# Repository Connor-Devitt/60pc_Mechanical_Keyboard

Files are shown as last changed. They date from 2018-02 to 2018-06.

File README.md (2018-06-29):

# 60pc_Mechanical_Keyboard
60% size mechanical keyboard design including PCB, frame, firmware. 

## The PCB (kiCAD)
* PCB uses a 60% keyboard layout
* Footprints for Cherry MX and clones.
* Microcontroller is ATmega32u4.
* Interfaces to PC over USB micro.

## The Frame (Inventor 2018)
* Made out of sheet aluminum
* Cutouts for cherry style stabilizers
* Approximatly 5 degree slope

## Versions
Version 1.0: Initial release
Version 1.1: Smaller form factor and improved differential routing

## Pictures (v1.0)
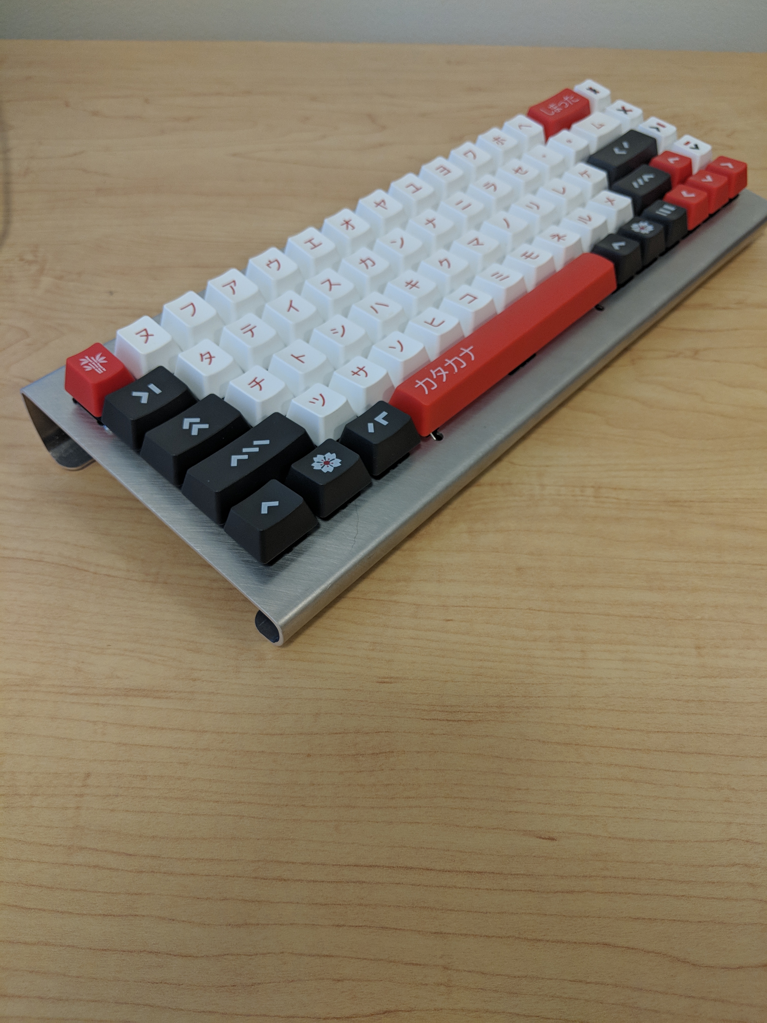
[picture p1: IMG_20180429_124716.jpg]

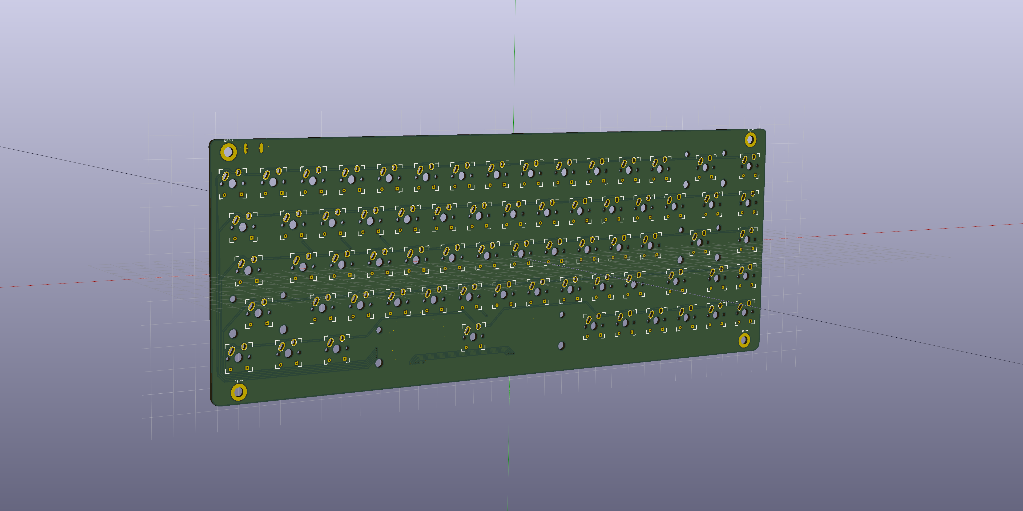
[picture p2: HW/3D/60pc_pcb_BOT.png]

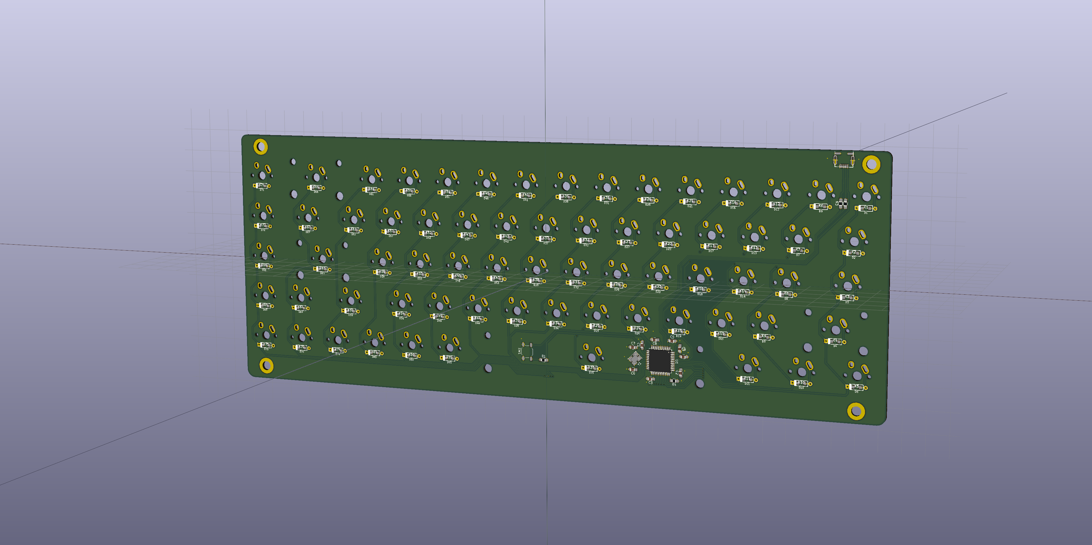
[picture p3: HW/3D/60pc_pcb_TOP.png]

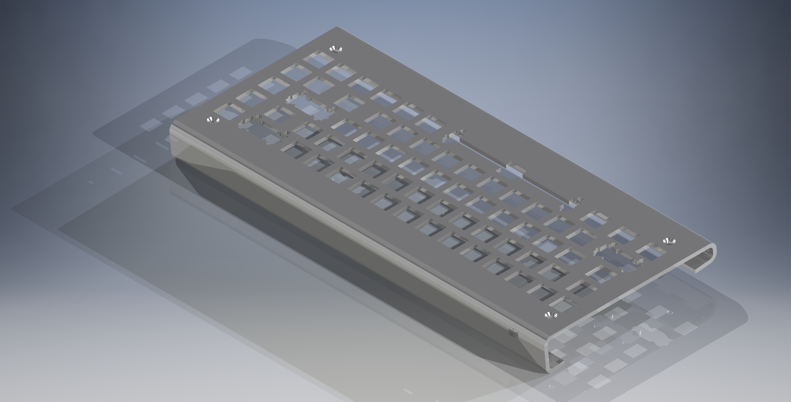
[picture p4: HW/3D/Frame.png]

Test

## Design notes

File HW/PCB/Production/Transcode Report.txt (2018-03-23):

   ---- Transcoding 'C:\Users\ConnorDevitt.MSI\Documents\Keyboard\60pc_Keeb\HW\PCB\Production\60pc_pcb.kicad_v1.1_pcb-B.Mask.gbs' ----   Tue Feb 20 21:41:09 2018

D11   --> D100
D12   --> D101
D13   --> D102
D14   --> D103
D15   --> D104
D16   --> D105
D17   --> D106
D18   --> D107
D19   --> D108
D20   --> D109
D21   --> D110
D22   --> D111
D23   --> D112
D24   --> D113
D25   --> D114
-----------------------------------------------------------------

   ---- Transcoding 'C:\Users\ConnorDevitt.MSI\Documents\Keyboard\60pc_Keeb\HW\PCB\Production\60pc_pcb.kicad_v1.1_pcb-B.Paste.gbp' ----   Tue Feb 20 21:41:09 2018

D11   --> D115
D12   --> D116
D13   --> D117
D14   --> D118
D15   --> D119
D16   --> D120
D17   --> D121
D18   --> D122
D19   --> D123
D20   --> D124
D21   --> D125
-----------------------------------------------------------------

   ---- Transcoding 'C:\Users\ConnorDevitt.MSI\Documents\Keyboard\60pc_Keeb\HW\PCB\Production\60pc_pcb.kicad_v1.1_pcb-B.SilkS.gbo' ----   Tue Feb 20 21:41:09 2018

D11   --> D126
D12   --> D127
D13   --> D128
-----------------------------------------------------------------

   ---- Transcoding 'C:\Users\ConnorDevitt.MSI\Documents\Keyboard\60pc_Keeb\HW\PCB\Production\60pc_pcb.kicad_v1.1_pcb-Edge.Cuts.gm1' ----   Tue Feb 20 21:41:09 2018

D11   --> D129
-----------------------------------------------------------------

   ---- Transcoding 'C:\Users\ConnorDevitt.MSI\Documents\Keyboard\60pc_Keeb\HW\PCB\Production\60pc_pcb.kicad_v1.1_pcb-F.Cu.gtl' ----   Tue Feb 20 21:41:09 2018

D12   --> D130
D13   --> D131
D14   --> D132
D15   --> D133
D16   --> D134
D17   --> D135
D18   --> D136
-----------------------------------------------------------------

   ---- Transcoding 'C:\Users\ConnorDevitt.MSI\Documents\Keyboard\60pc_Keeb\HW\PCB\Production\60pc_pcb.kicad_v1.1_pcb-F.Mask.gts' ----   Tue Feb 20 21:41:09 2018

D11   --> D137
D12   --> D138
D13   --> D139
D14   --> D140
D15   --> D141
-----------------------------------------------------------------

   ---- Transcoding 'C:\Users\ConnorDevitt.MSI\Documents\Keyboard\60pc_Keeb\HW\PCB\Production\60pc_pcb.kicad_v1.1_pcb-F.SilkS.gto' ----   Tue Feb 20 21:41:09 2018

D11   --> D142
D12   --> D143
-----------------------------------------------------------------

   ---- Transcoding 'C:\Users\ConnorDevitt.MSI\Documents\Keyboard\60pc_Keeb\HW\PCB\Production\60pc_pcb.kicad_v1.1_pcb-B.Mask.gbs' ----   Tue Feb 20 21:43:16 2018

D11   --> D100
D12   --> D101
D13   --> D102
D14   --> D103
D15   --> D104
D16   --> D105
D17   --> D106
D18   --> D107
D19   --> D108
D20   --> D109
D21   --> D110
D22   --> D111
D23   --> D112
D24   --> D113
D25   --> D114
-----------------------------------------------------------------

   ---- Transcoding 'C:\Users\ConnorDevitt.MSI\Documents\Keyboard\60pc_Keeb\HW\PCB\Production\60pc_pcb.kicad_v1.1_pcb-B.Paste.gbp' ----   Tue Feb 20 21:43:16 2018

D11   --> D115
D12   --> D116
D13   --> D117
D14   --> D118
D15   --> D119
D16   --> D120
D17   --> D121
D18   --> D122
D19   --> D123
D20   --> D124
D21   --> D125
-----------------------------------------------------------------

   ---- Transcoding 'C:\Users\ConnorDevitt.MSI\Documents\Keyboard\60pc_Keeb\HW\PCB\Production\60pc_pcb.kicad_v1.1_pcb-B.SilkS.gbo' ----   Tue Feb 20 21:43:16 2018

D11   --> D126
D12   --> D127
D13   --> D128
-----------------------------------------------------------------

   ---- Transcoding 'C:\Users\ConnorDevitt.MSI\Documents\Keyboard\60pc_Keeb\HW\PCB\Production\60pc_pcb.kicad_v1.1_pcb-Edge.Cuts.gm1' ----   Tue Feb 20 21:43:16 2018

D11   --> D129
-----------------------------------------------------------------

   ---- Transcoding 'C:\Users\ConnorDevitt.MSI\Documents\Keyboard\60pc_Keeb\HW\PCB\Production\60pc_pcb.kicad_v1.1_pcb-F.Cu.gtl' ----   Tue Feb 20 21:43:16 2018

D12   --> D130
D13   --> D131
D14   --> D132
D15   --> D133
D16   --> D134
D17   --> D135
D18   --> D136
-----------------------------------------------------------------

   ---- Transcoding 'C:\Users\ConnorDevitt.MSI\Documents\Keyboard\60pc_Keeb\HW\PCB\Production\60pc_pcb.kicad_v1.1_pcb-F.Mask.gts' ----   Tue Feb 20 21:43:16 2018

D11   --> D137
D12   --> D138
D13   --> D139
D14   --> D140
D15   --> D141
-----------------------------------------------------------------

   ---- Transcoding 'C:\Users\ConnorDevitt.MSI\Documents\Keyboard\60pc_Keeb\HW\PCB\Production\60pc_pcb.kicad_v1.1_pcb-F.SilkS.gto' ----   Tue Feb 20 21:43:16 2018

D11   --> D142
D12   --> D143
-----------------------------------------------------------------

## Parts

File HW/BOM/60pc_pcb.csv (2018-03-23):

Id | Designator | Package | Quantity | Designation | Supplier and ref
1 | K6,K1,K7,K8,K9,K12,K13,K14,K15,K16,K17,K18,K19,K21,K22,K23,K24,K26,K27,K28,K29,K31,K32,K33,K34,K36,K37,K38,K39,K41,K42,K43,K44,K46,K47,K48,K49,K51,K52,K53,K54,K55,K56,K57,K58,K60,K61,K62,K64,K65,K68,K69,K70,K71,K72,K75,K74 | Mx_Alps_100 | 57 | KEYSW
2 | U1 | TQFP-44_10x10mm_Pitch0.8mm | 1 | ATMEGA32U4
3 | C1,C2,C3,C4 | C_0805_HandSoldering | 4 | 0.1u
4 | C5 | C_0805_HandSoldering | 1 | 4.7u
5 | C6,C7 | C_0805_HandSoldering | 2 | 22p
6 | C8 | C_0805_HandSoldering | 1 | 1u
7 | C9 | C_0805_HandSoldering | 1 | 10n
8 | D1,D2,D3,D4,D5,D6,D7,D8,D9,D10,D11,D12,D13,D14,D15,D16,D17,D18,D19,D21,D22,D23,D24,D26,D27,D28,D29,D31,D32,D33,D34,D35,D36,D37,D38,D39,D41,D42,D43,D44,D46,D47,D48,D49,D51,D52,D53,D54,D55,D56,D57,D58,D60,D61,D62,D63,D64,D65,D66,D67,D68,D69,D70,D71,D72,D75,D74,D59 | D_SOD123_axial | 68 | D
9 | J1 | USB_miniB_hirose_5S8 | 1 | USB_mini_micro_B
10 | K2,K67 | Mx_Alps_150 | 2 | KEYSW
11 | K3,K59 | Mx_Alps_175 | 2 | KEYSW
12 | K4,K63 | Mx_Alps_225 | 2 | KEYSW
13 | K5,K10,K11 | Mx_Alps_125 | 3 | KEYSW
14 | K35 | Mx_Alps_625 | 1 | KEYSW
15 | K66 | Mx_Alps_200 | 1 | KEYSW
16 | R1,R4 | R_0805_HandSoldering | 2 | 10k
17 | R2,R3 | R_0805_HandSoldering | 2 | 22
18 | SW1 | SW_SPST_TL3342 | 1 | SW_PUSH
19 | Y1 | Crystal_SMD_SeikoEpson_TSX3225-4pin_3.2x2.5mm_HandSoldering | 1 | Crystal_GND24
20 | REF**,REF**,REF**,REF**,REF** | MountingHole_2.2mm_M2_ISO7380_Pad | 5 | MountingHole_2.2mm_M2_ISO7380_Pad

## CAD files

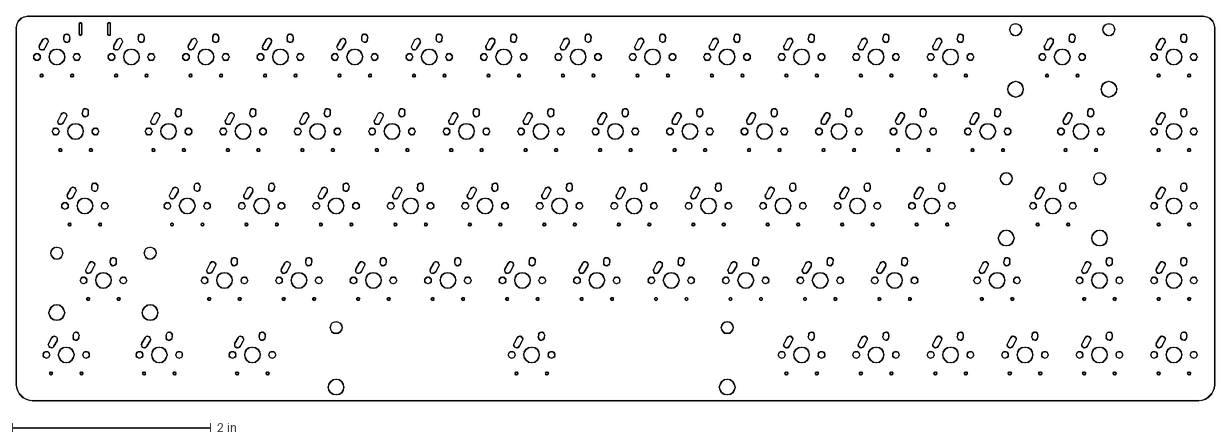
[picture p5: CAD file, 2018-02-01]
HW/3D/PCB_Sketch.dxf
12.1 x 3.87 in

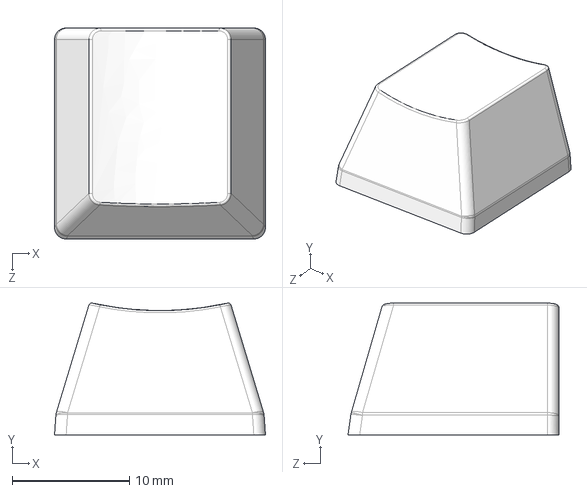
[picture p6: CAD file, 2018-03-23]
HW/Mech/MX 轴标准键帽.STEP
18.0 x 11.3 x 18.0 mm

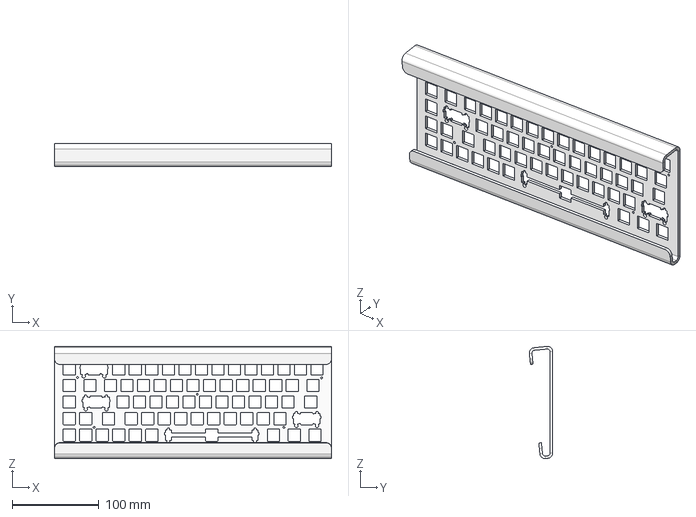
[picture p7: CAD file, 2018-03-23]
HW/Mech/Small_FormFactor(v1.1)/Frame_v1.1.stp
319.5 x 26.9 x 129.5 mm

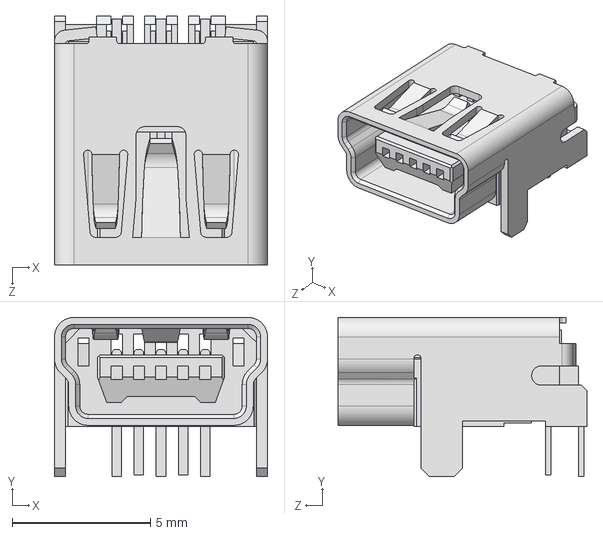
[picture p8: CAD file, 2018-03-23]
HW/Mech/User Library-USB-Mini-B.step
7.70 x 5.75 x 9.00 mm

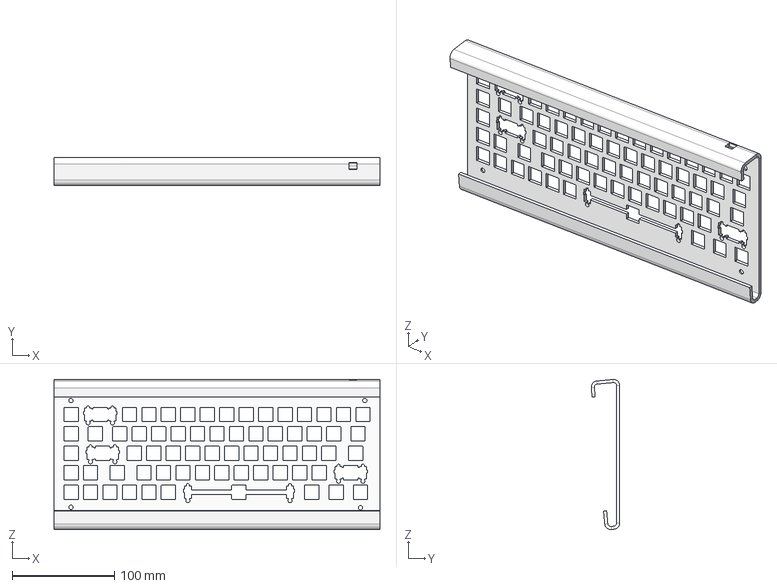
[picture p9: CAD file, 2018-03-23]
HW/Mech/Frame.step
319.2 x 27.9 x 146.9 mm

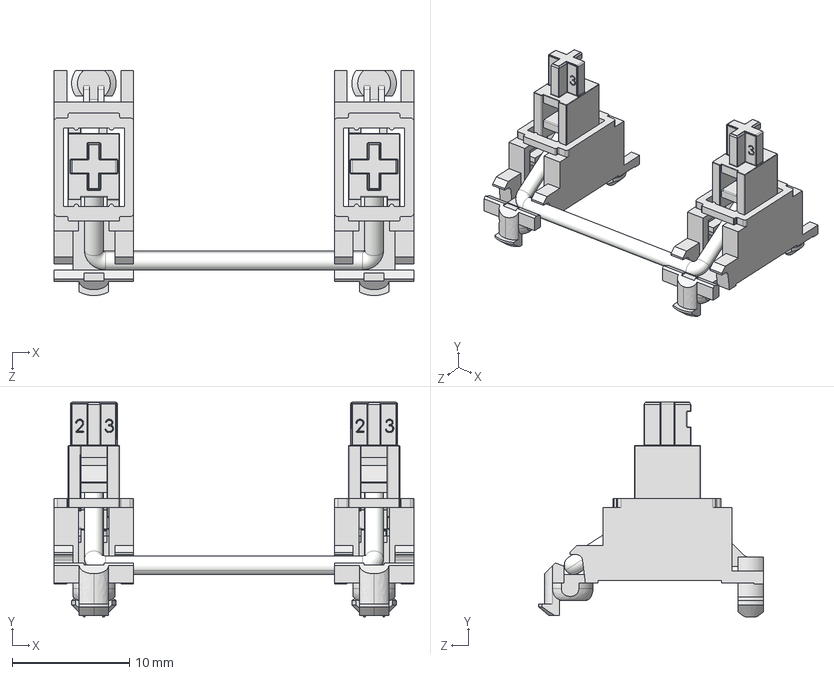
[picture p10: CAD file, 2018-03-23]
HW/Mech/Stabilizer - open.STEP
30.7 x 18.3 x 19.2 mm
mx Stabilizer base 16828 x 2
mx Stabilizer key 16828 x 2
metal stick 16828

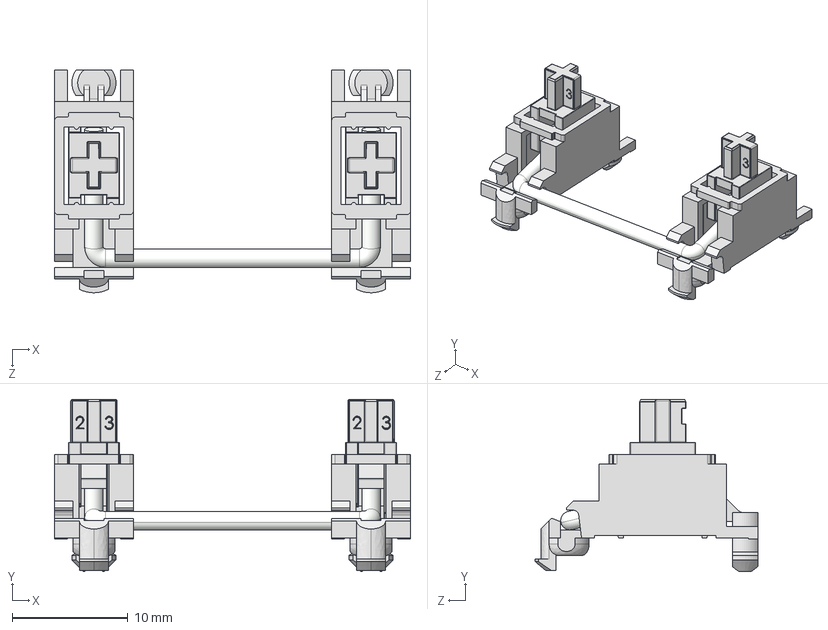
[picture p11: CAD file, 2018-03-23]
HW/Mech/Stabilizer - close.STEP
30.7 x 14.9 x 19.2 mm
mx Stabilizer base 16828 x 2
mx Stabilizer key 16828 x 2
metal stick 16828

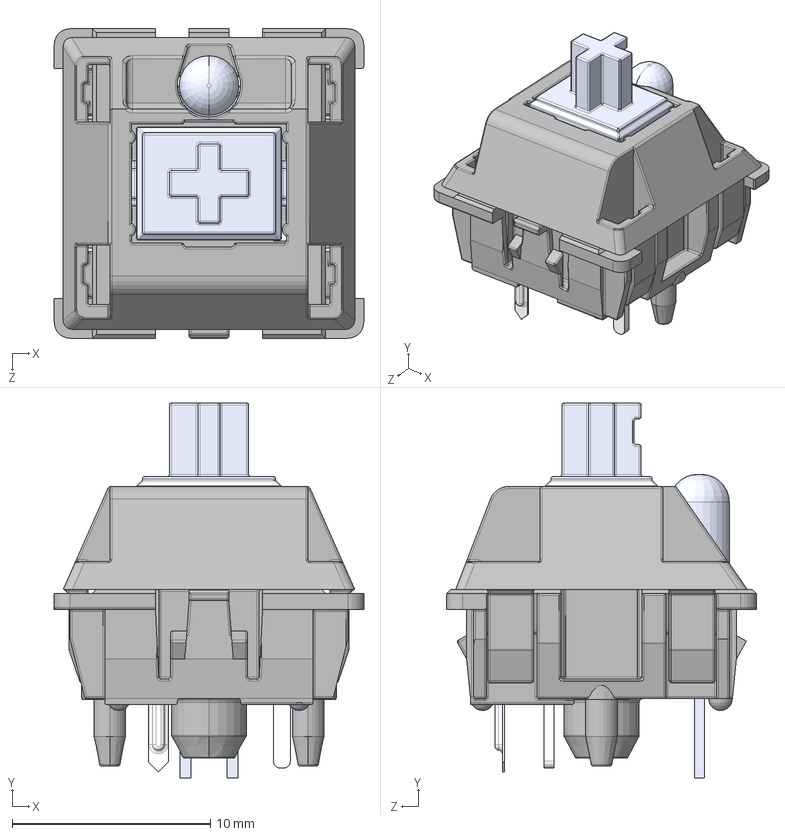
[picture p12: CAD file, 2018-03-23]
HW/Mech/MX .STEP
15.6 x 18.9 x 15.6 mm
MX 轴 按键′_ü___¨1
MX 轴 轴体áì_¨￠¨__
MX粣 拸簽LEDLEDLED
MX轴 轴体 底部 μ×2__默认_á2____è_
针脚___默认__è_

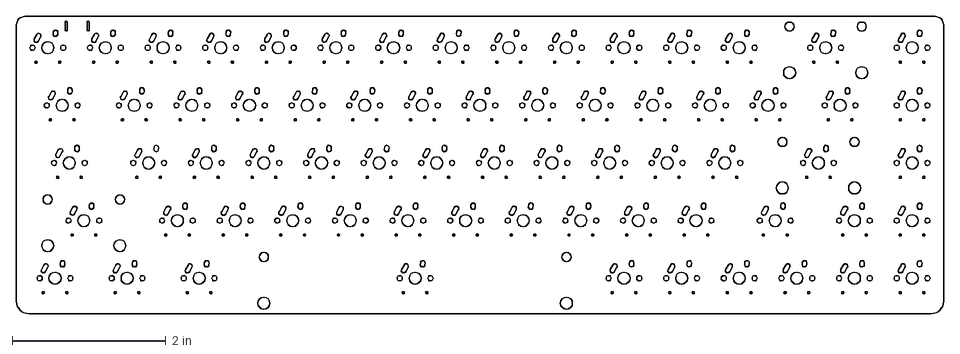
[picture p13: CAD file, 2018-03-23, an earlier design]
HW/Mech/OldVersions/PCB_Sketch.dxf
12.1 x 3.87 in

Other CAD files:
HW/3D/60pc_pcb.kicad_pcb.iam
HW/Mech/60pc_pcb.kicad_pcb_Outline.ipt
HW/Mech/Desk.ipt
HW/Mech/Frame.ipt
HW/Mech/Keeyboard_Assemply.iam
HW/Mech/MX .ipt
HW/Mech/OldVersions/60pc_pcb.kicad_pcb.iam
HW/Mech/OldVersions/60pc_pcb.kicad_pcb_Outline.0001.ipt
HW/Mech/OldVersions/60pc_pcb.kicad_pcb_Outline.ipt
HW/Mech/OldVersions/Frame.0009.ipt
HW/Mech/OldVersions/Frame.ipt
HW/Mech/OldVersions/Keeyboard_Assemply.0008.iam
HW/Mech/Small_FormFactor(v1.1)/60pc_keep_v1.1.ipt
HW/Mech/Small_FormFactor(v1.1)/60pc_keey_v1.1.iam
HW/Mech/Small_FormFactor(v1.1)/60pc_pcb.kicad_v1.1_pcb.kicad_pcb.ipt
HW/Mech/Small_FormFactor(v1.1)/Frame_v1.1.dxf
HW/Mech/Small_FormFactor(v1.1)/Frame_v1.1.ipt
HW/Mech/Small_FormFactor(v1.1)/OldVersions/Frame_v1.1.0007.ipt
HW/Mech/Stabilizer - close.ipt
HW/Mech/User Library-USB-Mini-B.ipt

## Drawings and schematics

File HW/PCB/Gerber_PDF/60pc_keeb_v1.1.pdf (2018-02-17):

60pc_pcb.kicad_v1.1_pcb-F.SilkS.gto Scale=1.35 Sat Feb 17 00:57:16 2018

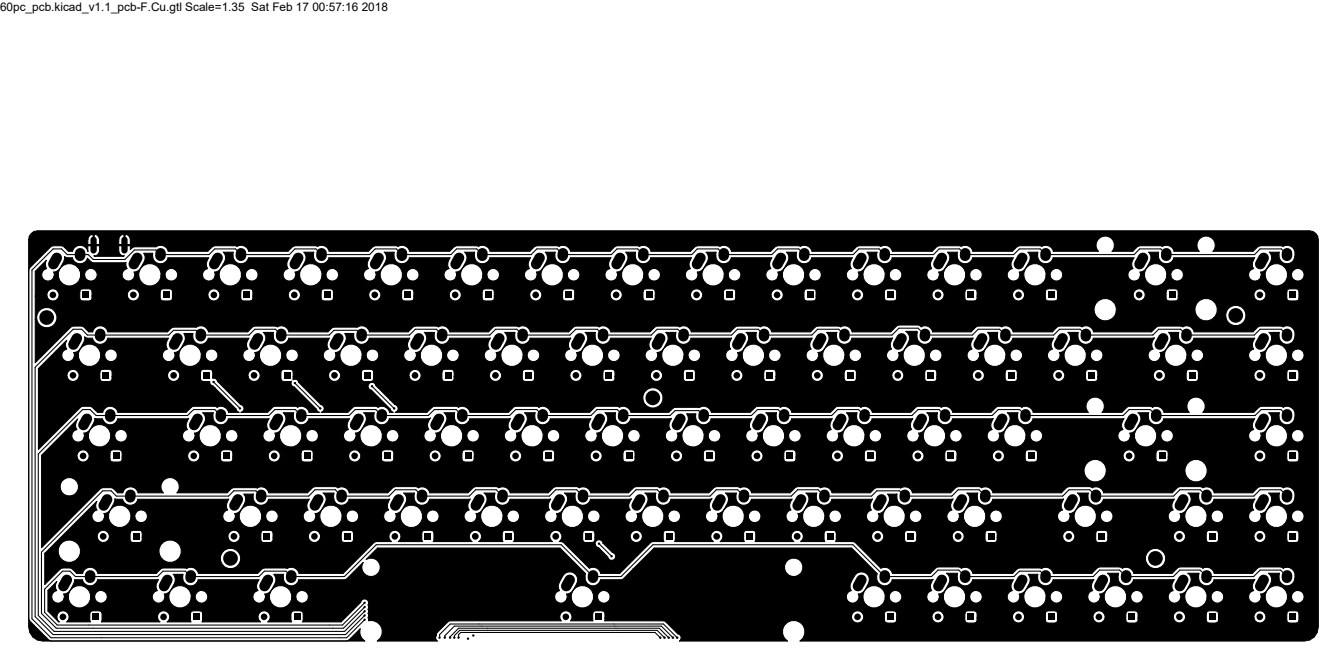
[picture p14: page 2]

60pc_pcb.kicad_v1.1_pcb-F.Cu.gtl Scale=1.35 Sat Feb 17 00:57:16 2018

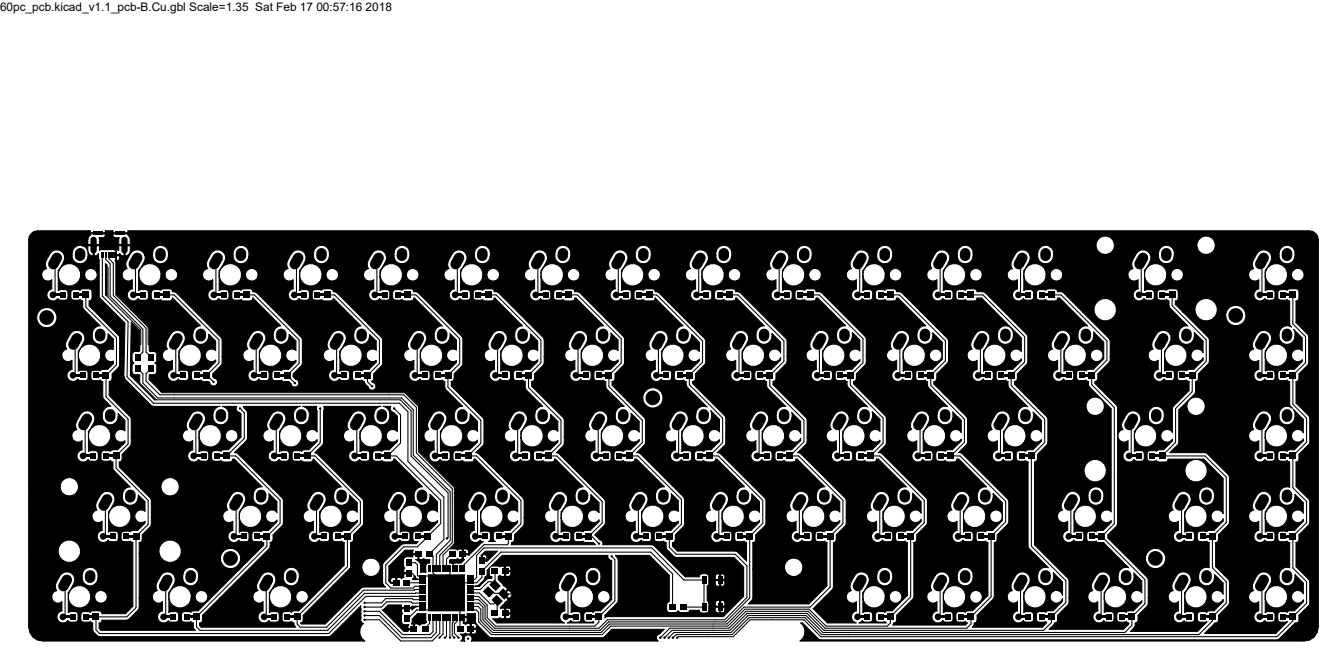
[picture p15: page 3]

60pc_pcb.kicad_v1.1_pcb-B.Cu.gbl Scale=1.35 Sat Feb 17 00:57:16 2018

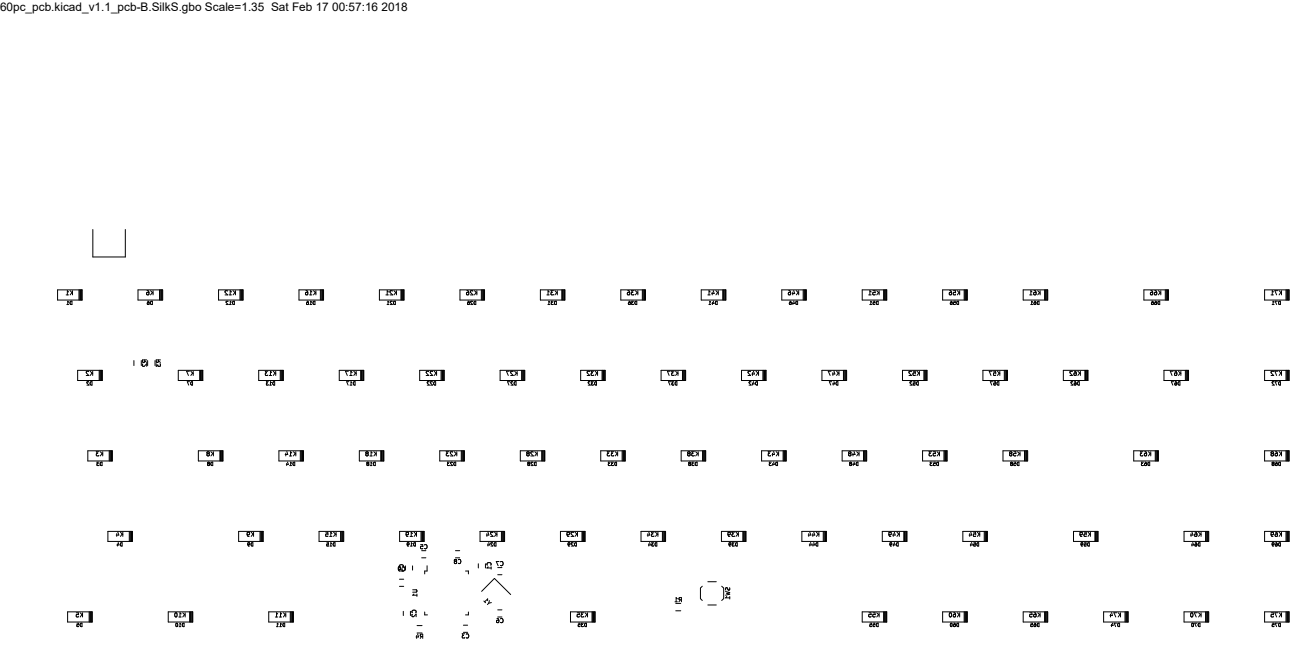
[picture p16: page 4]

60pc_pcb.kicad_v1.1_pcb-B.SilkS.gbo Scale=1.35 Sat Feb 17 00:57:16 2018

60pc_pcb.kicad_v1.1_pcb-Edge.Cuts.gm1 Scale=1.35 Sat Feb 17 00:57:16 2018

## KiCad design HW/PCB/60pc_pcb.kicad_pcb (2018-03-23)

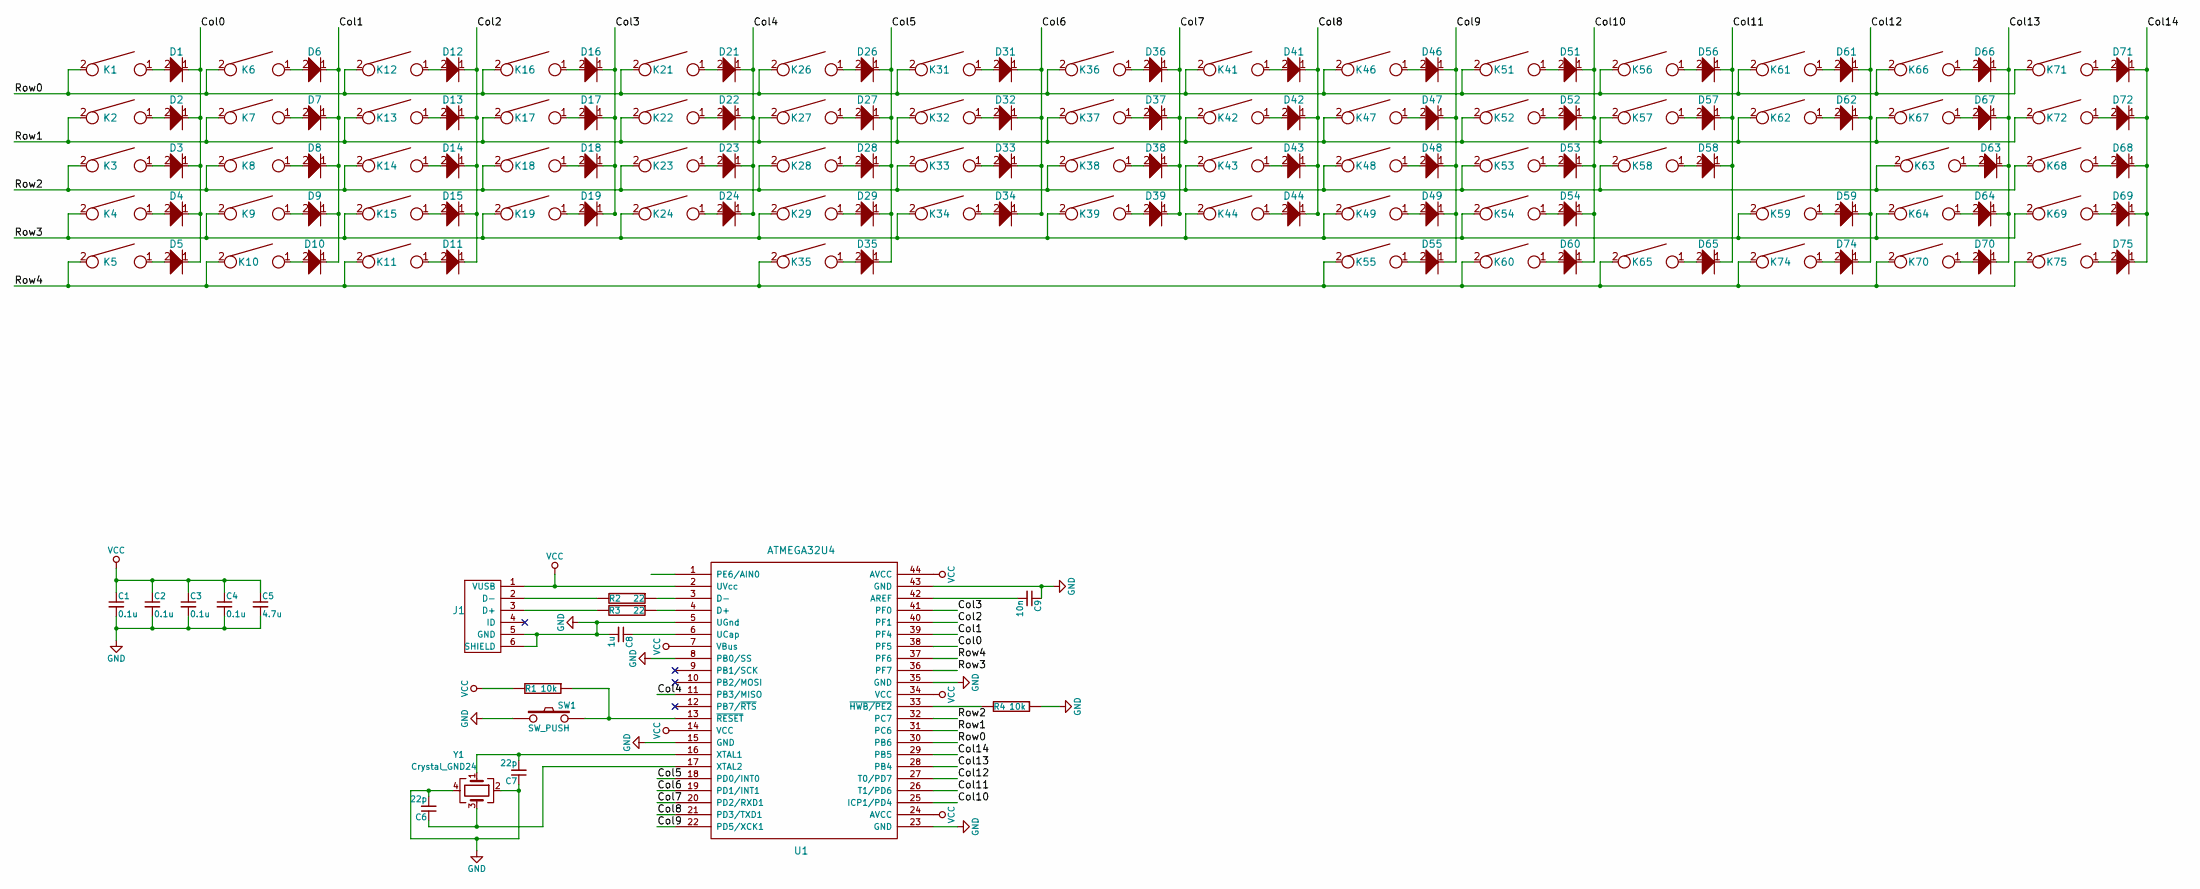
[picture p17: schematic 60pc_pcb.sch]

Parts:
C1, C2, C3, C4: 0.1u; C_0805_HandSoldering
C5: 4.7u; C_0805_HandSoldering
C6, C7: 22p; C_0805_HandSoldering
C8: 1u; C_0805_HandSoldering
C9: 10n; C_0805_HandSoldering
D1, D2, D3, D4, D5, D6, D7, D8, D9, D10, D11, D12, D13, D14, D15, D16, D17, D18, D19, D21, D22, D23, D24, D26, D27, D28, D29, D31, D32, D33, D34, D35, D36, D37, D38, D39, D41, D42, D43, D44, D46, D47, D48, D49, D51, D52, D53, D54, D55, D56, D57, D58, D59, D60, D61, D62, D63, D64, D65, D66, D67, D68, D69, D70, D71, D72, D74, D75: D; D_SOD123_axial
J1: USB_mini_micro_B; USB_miniB_hirose_5S8
K1, K6, K7, K8, K9, K12, K13, K14, K15, K16, K17, K18, K19, K21, K22, K23, K24, K26, K27, K28, K29, K31, K32, K33, K34, K36, K37, K38, K39, K41, K42, K43, K44, K46, K47, K48, K49, K51, K52, K53, K54, K55, K56, K57, K58, K60, K61, K62, K64, K65, K68, K69, K70, K71, K72, K74, K75: KEYSW; Mx_Alps_100
K2, K67: KEYSW; Mx_Alps_150
K3, K59: KEYSW; Mx_Alps_175
K4, K63: KEYSW; Mx_Alps_225
K5, K10, K11: KEYSW; Mx_Alps_125
K35: KEYSW; Mx_Alps_625
K66: KEYSW; Mx_Alps_200
R1, R4: 10k; R_0805_HandSoldering
R2, R3: 22; R_0805_HandSoldering
SW1: SW_PUSH; SW_SPST_TL3342
U1: ATMEGA32U4; TQFP-44_10x10mm_Pitch0.8mm
Y1: Crystal_GND24; Crystal_SMD_SeikoEpson_TSX3225-4pin_3.2x2.5mm_HandSoldering

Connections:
/Col0: D1.1, D2.1, D3.1, D4.1, D5.1, U1.38 (PF5)
/Col1: D6.1, D7.1, D8.1, D9.1, D10.1, U1.39 (PF4)
/Col2: D11.1, D12.1, D13.1, D14.1, D15.1, U1.40 (PF1)
/Col3: D16.1, D17.1, D18.1, D19.1, U1.41 (PF0)
/Col4: D21.1, D22.1, D23.1, D24.1, U1.11 (PB3/MISO)
/Col5: D26.1, D27.1, D28.1, D29.1, D35.1, U1.18 (PD0/INT0)
/Col6: D31.1, D32.1, D33.1, D34.1, U1.19 (PD1/INT1)
/Col7: D36.1, D37.1, D38.1, D39.1, U1.20 (PD2/RXD1)
/Col8: D41.1, D42.1, D43.1, D44.1, U1.21 (PD3/TXD1)
/Col9: D46.1, D47.1, D48.1, D49.1, D55.1, U1.22 (PD5/XCK1)
/Col10: D51.1, D52.1, D53.1, D54.1, D60.1, U1.25 (ICP1/PD4)
/Col11: D56.1, D57.1, D58.1, D65.1, U1.26 (T1/PD6)
/Col12: D59.1, D61.1, D62.1, D74.1, U1.27 (T0/PD7)
/Col13: D63.1, D64.1, D66.1, D67.1, D70.1, U1.28 (PB4)
/Col14: D68.1, D69.1, D71.1, D72.1, D75.1, U1.29 (PB5)
/Row0: K1.2, K6.2, K12.2, K16.2, K21.2, K26.2, K31.2, K36.2, K41.2, K46.2, K51.2, K56.2, K61.2, K66.2, K71.2, U1.30 (PB6)
/Row1: K2.2, K7.2, K13.2, K17.2, K22.2, K27.2, K32.2, K37.2, K42.2, K47.2, K52.2, K57.2, K62.2, K67.2, K72.2, U1.31 (PC6)
/Row2: K3.2, K8.2, K14.2, K18.2, K23.2, K28.2, K33.2, K38.2, K43.2, K48.2, K53.2, K58.2, K63.2, K68.2, U1.32 (PC7)
/Row3: K4.2, K9.2, K15.2, K19.2, K24.2, K29.2, K34.2, K39.2, K44.2, K49.2, K54.2, K59.2, K64.2, K69.2, U1.36 (PF7)
/Row4: K5.2, K10.2, K11.2, K35.2, K55.2, K60.2, K65.2, K70.2, K74.2, K75.2, U1.37 (PF6)
GND: C1.2, C2.2, C3.2, C4.2, C5.2, C6.2, C7.1, C8.2, C9.1, J1.5 (GND), J1.6 (SHIELD), R4.1, SW1.1, U1.5 (UGnd), U1.8 (PB0/SS), U1.15 (GND), U1.23 (GND), U1.35 (GND), U1.43 (GND), Y1.2, Y1.4
unnamed: C6.1, U1.17 (XTAL2), Y1.3
unnamed: C7.2, U1.16 (XTAL1), Y1.1
unnamed: C8.1, U1.6 (UCap)
unnamed: C9.2, U1.42 (AREF)
unnamed: D1.2, K1.1
unnamed: D2.2, K2.1
unnamed: D3.2, K3.1
unnamed: D4.2, K4.1
unnamed: D5.2, K5.1
unnamed: D6.2, K6.1
unnamed: D7.2, K7.1
unnamed: D8.2, K8.1
unnamed: D9.2, K9.1
unnamed: D10.2, K10.1
unnamed: D11.2, K11.1
unnamed: D12.2, K12.1
unnamed: D13.2, K13.1
unnamed: D14.2, K14.1
unnamed: D15.2, K15.1
unnamed: D16.2, K16.1
unnamed: D17.2, K17.1
unnamed: D18.2, K18.1
unnamed: D19.2, K19.1
unnamed: D21.2, K21.1
unnamed: D22.2, K22.1
unnamed: D23.2, K23.1
unnamed: D24.2, K24.1
unnamed: D26.2, K26.1
unnamed: D27.2, K27.1
unnamed: D28.2, K28.1
unnamed: D29.2, K29.1
unnamed: D31.2, K31.1
unnamed: D32.2, K32.1
unnamed: D33.2, K33.1
unnamed: D34.2, K34.1
unnamed: D35.2, K35.1
unnamed: D36.2, K36.1
unnamed: D37.2, K37.1
unnamed: D38.2, K38.1
unnamed: D39.2, K39.1
unnamed: D41.2, K41.1
unnamed: D42.2, K42.1
unnamed: D43.2, K43.1
unnamed: D44.2, K44.1
unnamed: D46.2, K46.1
unnamed: D47.2, K47.1
unnamed: D48.2, K48.1
unnamed: D49.2, K49.1
unnamed: D51.2, K51.1
unnamed: D52.2, K52.1
unnamed: D53.2, K53.1
unnamed: D54.2, K54.1
unnamed: D55.2, K55.1
unnamed: D56.2, K56.1
unnamed: D57.2, K57.1
unnamed: D58.2, K58.1
unnamed: D59.2, K59.1
unnamed: D60.2, K60.1
unnamed: D61.2, K61.1
unnamed: D62.2, K62.1
unnamed: D63.2, K63.1
unnamed: D64.2, K64.1
unnamed: D65.2, K65.1
unnamed: D66.2, K66.1
unnamed: D67.2, K67.1
unnamed: D68.2, K68.1
unnamed: D69.2, K69.1
unnamed: D70.2, K70.1
unnamed: D71.2, K71.1
unnamed: D72.2, K72.1
unnamed: D74.2, K74.1
unnamed: D75.2, K75.1
unnamed: J1.2 (D-), R2.2
unnamed: J1.3 (D+), R3.2
unnamed: R1.1, SW1.2, U1.13 (~RESET)
unnamed: R2.1, U1.3 (D-)
unnamed: R3.1, U1.4 (D+)
unnamed: R4.2, U1.33 (~HWB/PE2)
VCC: C1.1, C2.1, C3.1, C4.1, C5.1, J1.1 (VUSB), R1.2, U1.2 (UVcc), U1.7 (VBus), U1.14 (VCC), U1.24 (AVCC), U1.34 (VCC), U1.44 (AVCC)

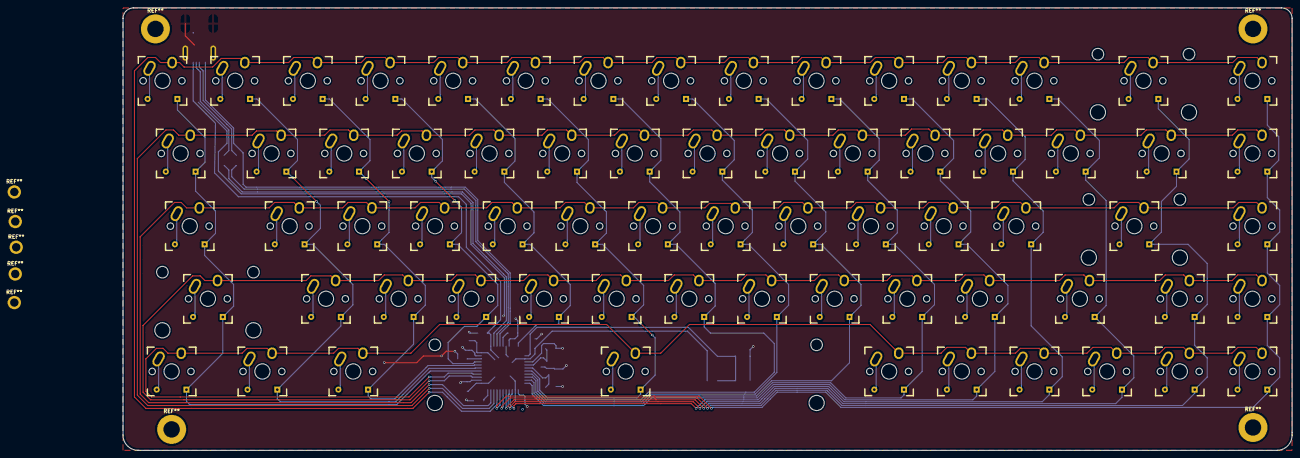
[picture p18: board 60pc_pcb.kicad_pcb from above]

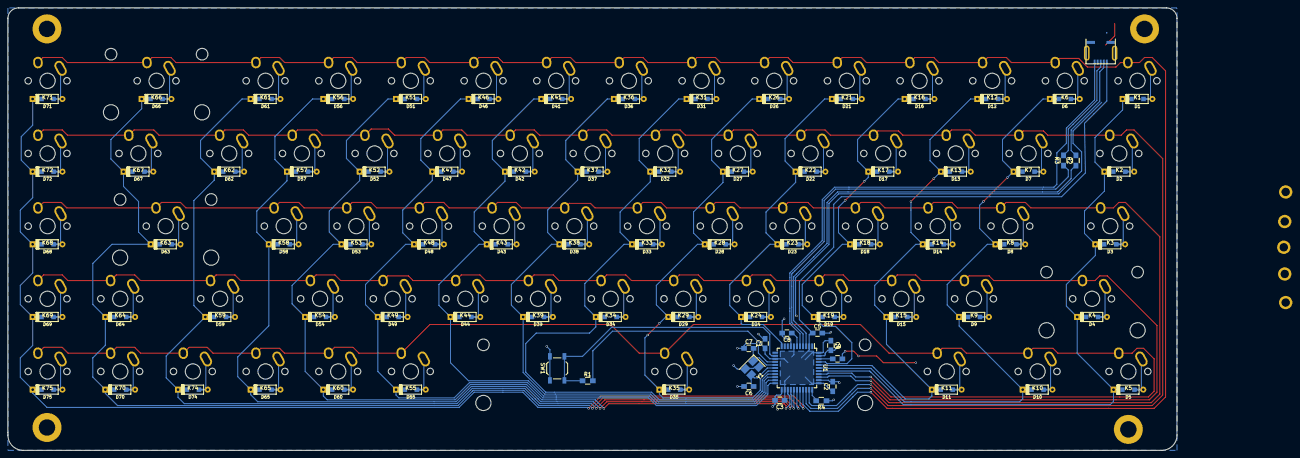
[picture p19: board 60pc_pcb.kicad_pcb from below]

Board: 2 copper layers, 306.5 x 116.0 mm, 153 parts (85 on the bottom side), 100 nets.

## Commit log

2018-02-01 Inventor project setup
    [Frame.ipt, PCB_Sketch.dxf]
2018-02-04 Added M4 mounting holes to pcb
    [60pc_pcb.kicad_pcb, 60pc_pcb.kicad_pcb_Outline.0001.ipt, 60pc_pcb.kicad_pcb_Outline.ipt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]
2018-02-05 3D updates
    New 3d pcb and frame top outline
    [60pc_pcb.kicad_pcb, 60pc_pcb.kicad_pcb.iam, 60pc_pcb.kicad_pcb_Outline.ipt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]
2018-02-05 Added frame cutouts
    [Frame.0001.ipt, Frame.0005.ipt, Frame.ipt]
2018-02-08 Frame part near compeltion
    [60pc_pcb.kicad_pcb, Frame.0005.ipt, Frame.0007.ipt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]
2018-02-10 Frame and Assembly finished
    [60pc_pcb.kicad_pcb, Desk.ipt, Frame.0007.ipt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]
2018-02-17 Version 1.1 edits
    Smaller form factor.
    4x M4 screws to 5x M2 screws.
    Screws now placed between switched.
    Dufferential routing return path and impedance matching improved.
    [60pc_keep_v1.1.ipt, 60pc_keey_v1.1.iam, 60pc_pcb.kicad_pcb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]
2018-02-25 Added Usb hole to v1.1
    [60pc_pcb.kicad_v1.1_pcb.kicad_pcb, Frame_v1.1.0001.ipt, Frame_v1.1.0002.ipt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]
2018-02-25 Preparations for CNC
    [Frame_v1.1.0006.ipt, Frame_v1.1.0007.ipt, Frame_v1.1.dxf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]
2018-03-23 Finished up hardware changes, setup SW project
    [60pc_pcb.csv, 60pc_pcb.kicad_pcb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]
